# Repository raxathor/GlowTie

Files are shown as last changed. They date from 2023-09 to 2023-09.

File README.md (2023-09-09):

# Glowtie
## The light-up bowtie you control over Wifi!

This project/repository is inspired by Stephen Hawes.
https://www.youtube.com/@stephen_hawes
https://github.com/sphawes/glowtie
https://stephenhawes.com/glowtie/



Welcome to the source for the [Glowtie](http://glowtie.io)! The Glowtie is a light-up bowtie you control over Wifi. The onboard ESP8266 puts out an access point network you can connect to with your phone. Navigate to 192.168.4.1 in your browser and you'll find the Glowtie control page, where you can change the colors and the patterns of the lights.



This Github repository holds all the information needed to create a bowtie, from 3D models to schematics. This page will be helpful if you're looking to recreate the glowtie, or hack it!

For more information about the Glowtie, check out Glowtie.io.

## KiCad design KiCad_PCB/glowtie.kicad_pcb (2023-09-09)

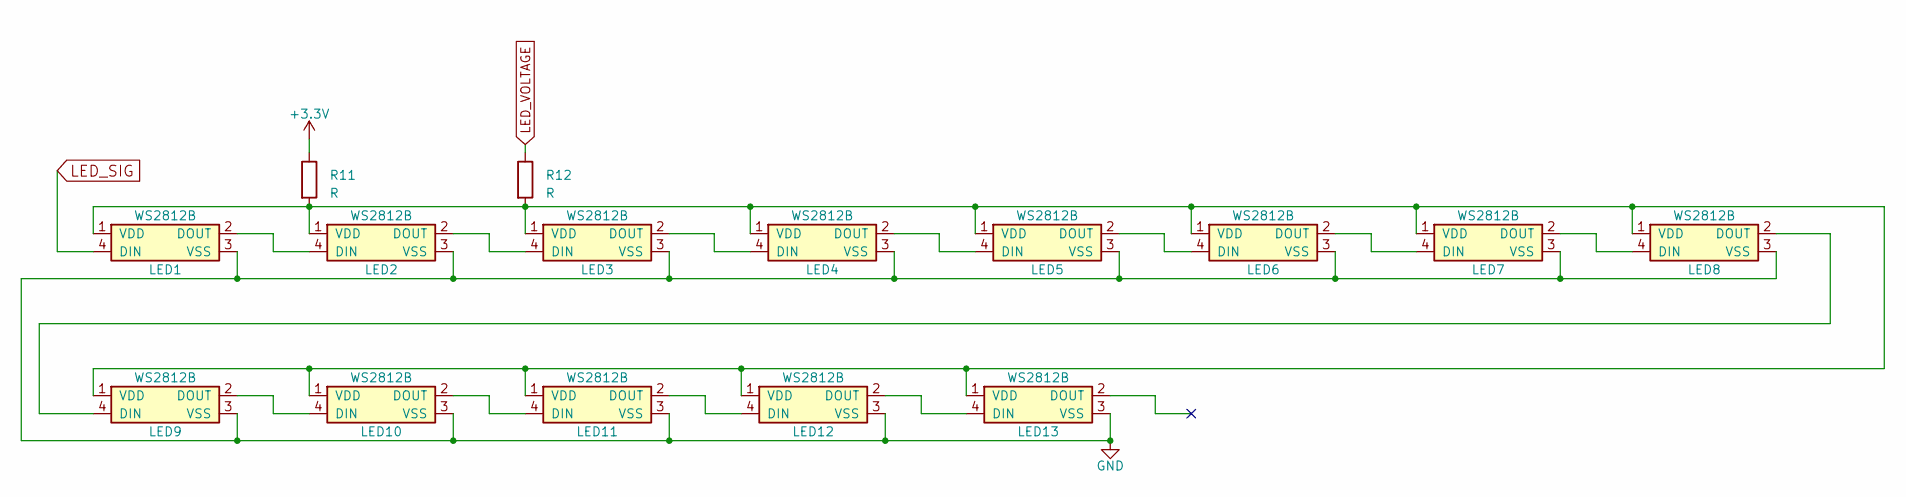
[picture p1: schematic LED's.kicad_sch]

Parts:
LED1, LED2, LED3, LED4, LED5, LED6, LED7, LED8, LED9, LED10, LED11, LED12, LED13: WS2812B
R11, R12: R; R_0603_1608Metric

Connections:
+3V3: R11.1; also elsewhere on the board
GND: LED1.3 (VSS), LED2.3 (VSS), LED3.3 (VSS), LED4.3 (VSS), LED5.3 (VSS), LED6.3 (VSS), LED7.3 (VSS), LED8.3 (VSS), LED9.3 (VSS), LED10.3 (VSS), LED11.3 (VSS), LED12.3 (VSS), LED13.3 (VSS); also elsewhere on the board
LED_SIG: LED1.4 (DIN); also elsewhere on the board
LED_VOLTAGE: R12.1; also elsewhere on the board
unnamed: LED1.2 (DOUT), LED2.4 (DIN)
unnamed: LED1.1 (VDD), LED2.1 (VDD), LED3.1 (VDD), LED4.1 (VDD), LED5.1 (VDD), LED6.1 (VDD), LED7.1 (VDD), LED8.1 (VDD), LED9.1 (VDD), LED10.1 (VDD), LED11.1 (VDD), LED12.1 (VDD), LED13.1 (VDD), R11.2, R12.2
unnamed: LED2.2 (DOUT), LED3.4 (DIN)
unnamed: LED3.2 (DOUT), LED4.4 (DIN)
unnamed: LED4.2 (DOUT), LED5.4 (DIN)
unnamed: LED5.2 (DOUT), LED6.4 (DIN)
unnamed: LED6.2 (DOUT), LED7.4 (DIN)
unnamed: LED7.2 (DOUT), LED8.4 (DIN)
unnamed: LED8.2 (DOUT), LED9.4 (DIN)
unnamed: LED9.2 (DOUT), LED10.4 (DIN)
unnamed: LED10.2 (DOUT), LED11.4 (DIN)
unnamed: LED11.2 (DOUT), LED12.4 (DIN)
unnamed: LED12.2 (DOUT), LED13.4 (DIN)

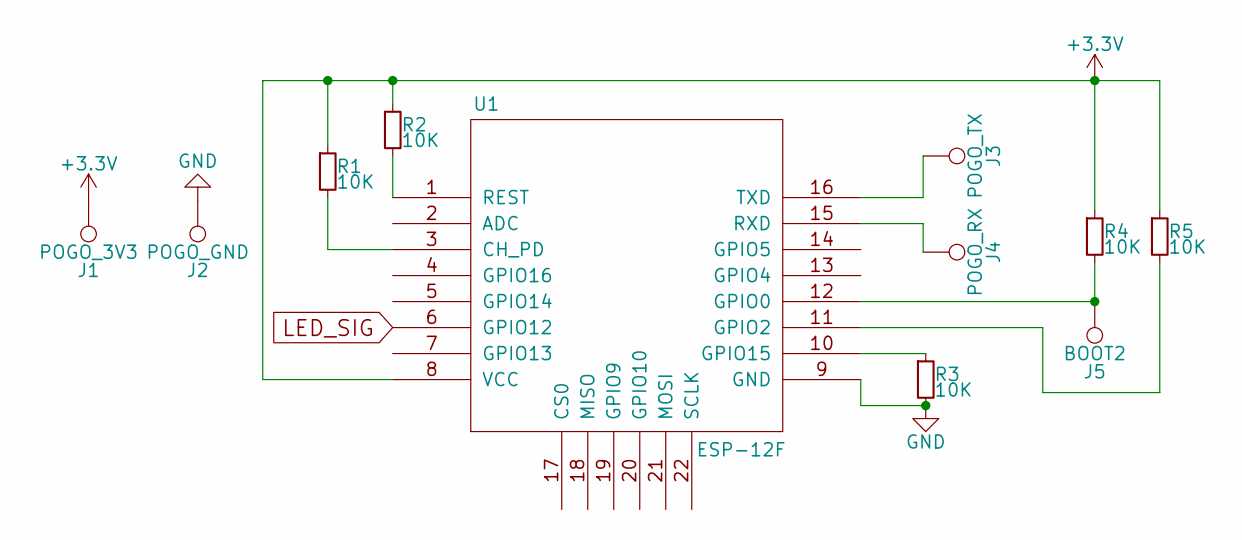
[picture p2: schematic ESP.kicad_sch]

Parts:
J1: POGO_3V3; TestPoint_Pad_D1.5mm
J2: POGO_GND; TestPoint_Pad_D1.5mm
J3: POGO_TX; TestPoint_Pad_D1.5mm
J4: POGO_RX; TestPoint_Pad_D1.5mm
J5: BOOT2; TestPoint_Pad_D1.5mm
R1, R2, R3, R4, R5: 10K; R_0805_2012Metric_Pad1.20x1.40mm_HandSolder
U1: ESP-12F; ESP-12E_SMD

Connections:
+3V3: J1.1, R1.1, R2.1, R4.1, R5.1, U1.8 (VCC); also elsewhere on the board
GND: J2.1, R3.2, U1.9 (GND); also elsewhere on the board
LED_SIG: U1.6 (GPIO12); also elsewhere on the board
unnamed: R1.2, U1.3 (CH_PD)
unnamed: J5.1, R4.2, U1.12 (GPIO0)
unnamed: R5.2, U1.11 (GPIO2)
unnamed: R3.1, U1.10 (GPIO15)
unnamed: R2.2, U1.1 (REST)
unnamed: J4.1, U1.15 (RXD)
unnamed: J3.1, U1.16 (TXD)

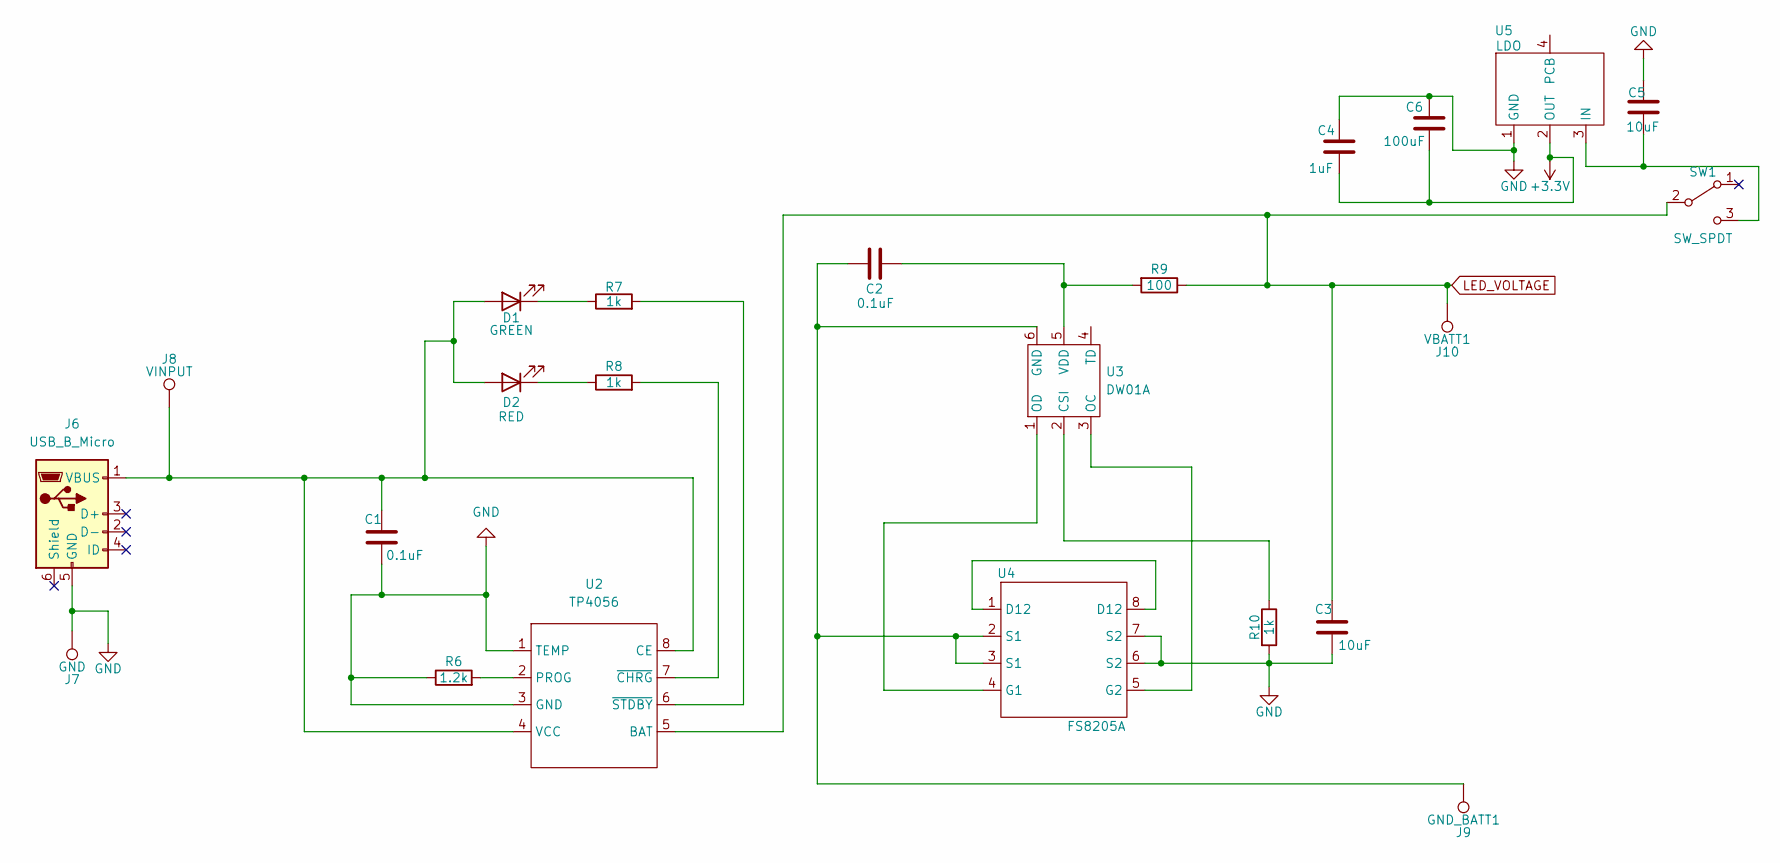
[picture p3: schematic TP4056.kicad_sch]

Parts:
C1, C2: 0.1uF; C_0805_2012Metric_Pad1.18x1.45mm_HandSolder
C3: 10uF; C_0805_2012Metric_Pad1.18x1.45mm_HandSolder
C4: 1uF; C_0805_2012Metric_Pad1.18x1.45mm_HandSolder
C5: 10uF; Tantalum_10uF
C6: 100uF; Tantalum_100uF
D1: GREEN; LED_0805_2012Metric_Pad1.15x1.40mm_HandSolder
D2: RED; LED_0805_2012Metric_Pad1.15x1.40mm_HandSolder
J6: USB_B_Micro; USB_Micro-B_Molex-105017-0001
J7: GND; TestPoint_Pad_D1.5mm
J8: VINPUT; TestPoint_Pad_D1.5mm
J9: GND_BATT1; TestPoint_Pad_D1.5mm
J10: VBATT1; TestPoint_Pad_D1.5mm
R6: 1.2k; R_0805_2012Metric_Pad1.20x1.40mm_HandSolder
R7, R8, R10: 1k; R_0805_2012Metric_Pad1.20x1.40mm_HandSolder
R9: 100; R_0805_2012Metric_Pad1.20x1.40mm_HandSolder
SW1: SW_SPDT; MSK12C02
U2: TP4056
U3: DW01A
U4: FS8205A
U5: LDO; AMS1117-3.3

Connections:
+3V3: C4.1, C6.1, U5.2 (OUT); also elsewhere on the board
GND: C1.2, C3.2, C4.2, C5.1, C6.2, J6.5 (GND), J7.1, R6.1, R10.2, U2.1 (TEMP), U2.3 (GND), U4.6 (S2), U4.7 (S2), U5.1 (GND); also elsewhere on the board
LED_VOLTAGE: C3.1, J10.1, R9.1, SW1.2 (B), U2.5 (BAT); also elsewhere on the board
unnamed: C1.1, D1.2 (A), D2.2 (A), J6.1 (VBUS), J8.1, U2.4 (VCC), U2.8 (CE)
unnamed: D1.1 (K), R7.1
unnamed: D2.1 (K), R8.1
unnamed: C5.2, SW1.3 (C), U5.3 (IN)
unnamed: R6.2, U2.2 (PROG)
unnamed: R8.2, U2.7 (~CHRG)
unnamed: R7.2, U2.6 (~STDBY)
unnamed: R10.1, U3.2 (CSI)
unnamed: C2.1, J9.1, U3.6 (GND), U4.2 (S1), U4.3 (S1)
unnamed: U3.3 (OC), U4.5 (G2)
unnamed: U3.1 (OD), U4.4 (G1)
unnamed: C2.2, R9.2, U3.5 (VDD)
unnamed: U4.1 (D12), U4.8 (D12)

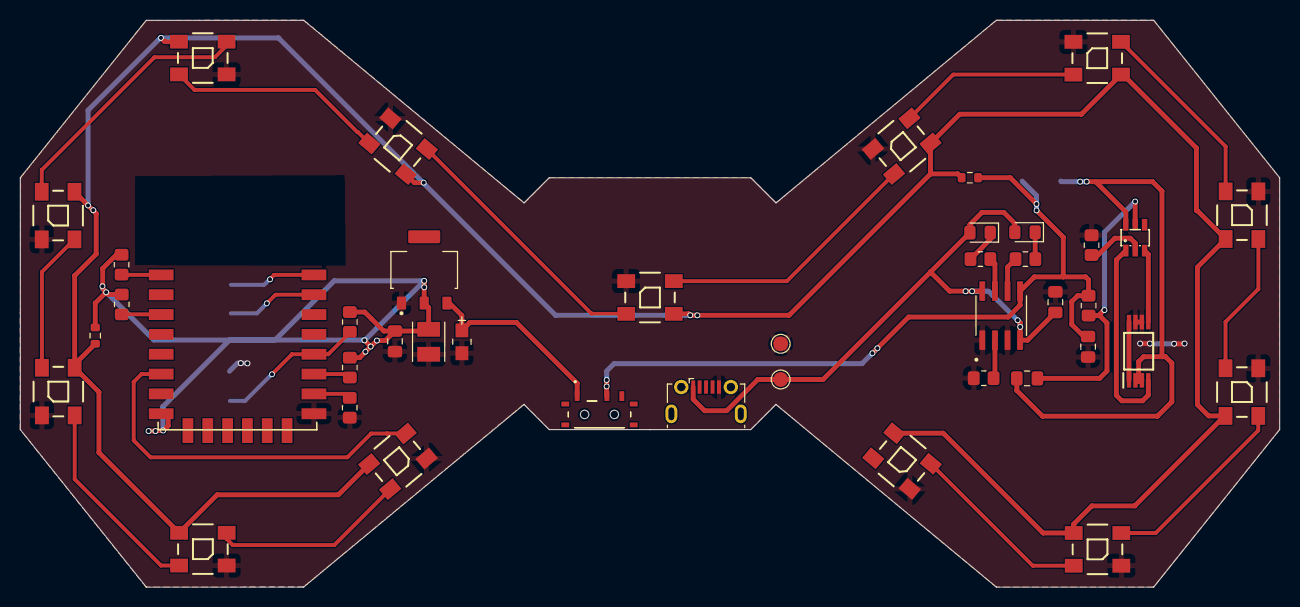
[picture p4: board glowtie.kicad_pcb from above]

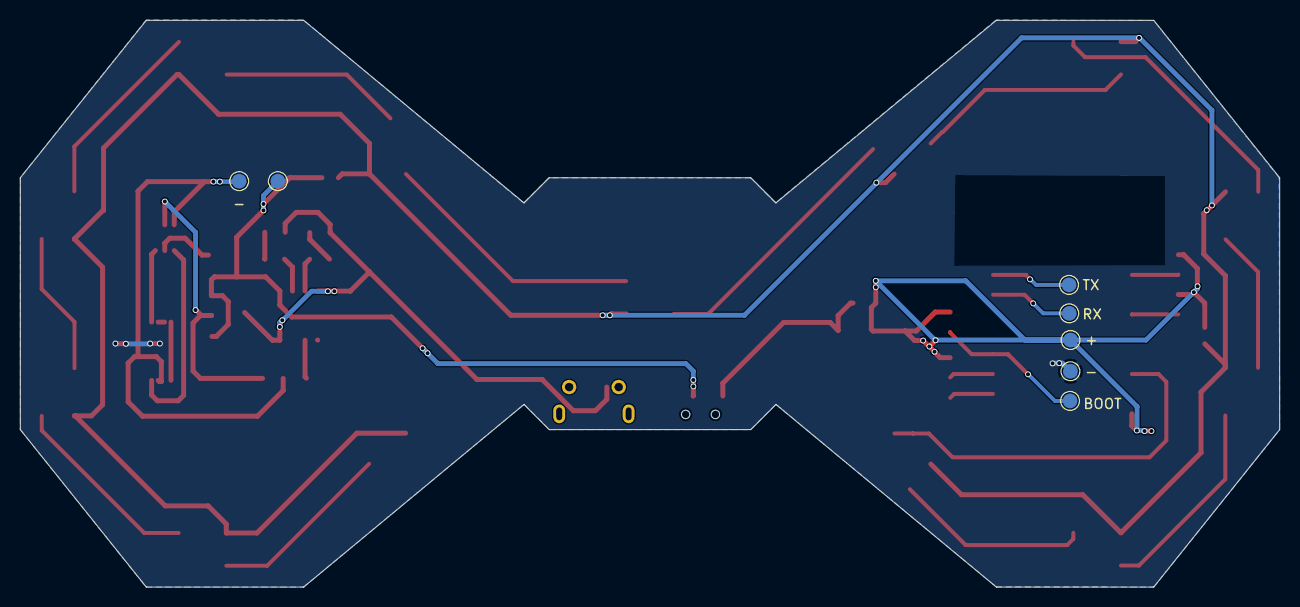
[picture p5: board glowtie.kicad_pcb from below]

Board: 2 copper layers, 127.0 x 57.2 mm, 49 parts (7 on the bottom side), 37 nets.

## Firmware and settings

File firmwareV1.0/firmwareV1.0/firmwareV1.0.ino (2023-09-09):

//Glowtie Firmware v1.0
//Stephen Hawes 2019
//TOOLS:
//Stringify HTML file:
//http://davidjwatts.com/youtube/esp8266/esp-convertHTM.html#
//Reference for sending data between site and server
//https://bitbucket.org/Remnis/neopixelwebserver/src/0ae6ce3b2122?at=master
//https://github.com/jasoncoon/esp8266-fastled-webserver/blob/master/data/index.htm

#include <Adafruit_NeoPixel.h>
#include <ESP8266WiFi.h>
#include <WiFiClient.h>
#include <ESP8266WebServer.h>
#include <EEPROM.h>

#define PIN            12
#define NUMPIXELS      13

#define SN "PizzaBowtie"

Adafruit_NeoPixel pixels = Adafruit_NeoPixel(NUMPIXELS, PIN, NEO_GRB + NEO_KHZ800);

ADC_MODE(ADC_VCC);

const char *ssid = SN;
const char *password = "pleaseletmein";

ESP8266WebServer server(80);

int const battCacheSize = 30;
int battCachePosition = 0;
int battCache[battCacheSize] = {3300, 3300, 3300, 3300, 3300, 3300, 3300, 3300, 3300, 3300, 3300, 3300, 3300, 3300, 3300, 3300, 3300, 3300, 3300, 3300, 3300, 3300, 3300, 3300, 3300, 3300, 3300, 3300, 3300, 3300};
int summedCache = 99000;
float avgBatt = 3300;
int newBatt = 0;

int delayVal = 8;
int btMode = 0;
int rVal = 0;
int gVal = 0;
int bVal = 0;
int brightness = 30;
int checkBattTimer = 0;
int prevMode = 0;

int ba = 0;
int bb = 0;
int bc = 0;
int bd = 0;
int bi = 0;

int pa = 0;
int pi = 0;

int ii = 0;

unsigned long prevMillis = millis();

void setup() {
  Serial.begin(115200);

  pixels.begin();

  //storing 4 eeprom values. the 0th is the saved mode, then the 1-3th are r, g, and b values, respectively. 4 bytes per int with 4 ints is 16 bytes:
  EEPROM.begin(512);

  btMode = EEPROM.read(0);
  rVal = EEPROM.read(4);
  gVal = EEPROM.read(8);
  bVal = EEPROM.read(12);

  //CHECKING BATTERY

  newBatt = ESP.getVcc();
  if (newBatt <= 3100) {
    btMode = 1;
    Serial.println("Battery low, going into low battery mode.");
  }

  //Animation
  for (int j = 0; j < 300; j++) {
    burst(50, 20, 0);
    delay(10);
  }

  //WIFI JAZZ
  Serial.print("Creating Glowtie netowork...");
  if (WiFi.softAP(ssid)) {
    Serial.println("Successfully started access point.");
  }
  else {
    Serial.println("Could not start access point.");
  }

  IPAddress myIP = WiFi.softAPIP();
  Serial.print("IP address: ");
  Serial.println(myIP);

  server.on("/", handleRoot);
  server.begin();

  //END WIFI STUFF

  checkBattTimer = millis();

}



void loop() {
  //yield();
  server.handleClient();
  //Checking battery value

  if (millis() >= checkBattTimer + 5000) {
    newBatt = ESP.getVcc();
    Serial.println(newBatt);
    if (newBatt <= 3100) {
      btMode = 1;
    }
    checkBattTimer = millis();
  }


  //OFF MODE
  if (btMode == 0) {
    if (prevMode != 0) {
      off();
      prevMode = 0;
    }
  }

  //LOW BATTERY MODE
  else if (btMode == 1) {
    if (prevMode != 1) {
      lowBatt();
      prevMode = 1;
    }
  }

  //SOLID COLOR MODE
  else if (btMode == 2) {
    if (prevMode != 2) {
      solid();
      prevMode = 2;
    }
  }

  //INFINITY MODE
  else if (btMode == 3) {
    if (prevMode != 3) {
      prevMillis = millis() - 71;
      prevMode = 3;
      ii = 0;
    }
    if (millis() > prevMillis + 70) {
      prevMillis = millis();
      infin(rVal, gVal, bVal);
    }
  }

  //PULSE MODE
  else if (btMode == 4) {
    if (prevMode != 4) {
      pi = 0;
      prevMode = 4;
    }
    if (millis() > prevMillis + 7) {
      prevMillis = millis();
      pulse(rVal, gVal, bVal);
    }
  }

  //BURST MODE
  else if (btMode == 5) {
    if (prevMode != 5) {
      bi = 0;
      prevMode = 5;
    }
    if (millis() > prevMillis + 10) {
      //Burst mode
      prevMillis = millis();
      burst(rVal, gVal, bVal);
    }
  }
}

void handleRoot() {
  //off();

  if (server.args() > 0) {
    int r = server.arg("red").toInt();
    int g = server.arg("green").toInt();
    int b = server.arg("blue").toInt();
    String btModeS = server.arg("mode");
    btMode = btModeS.toInt();

    int red = r / 3;
    int green = g / 3;
    int blue = b / 3;

    rVal = red;
    gVal = green;
    bVal = blue;

    EEPROM.write(0, btMode);
    EEPROM.write(4, rVal);
    EEPROM.write(8, gVal);
    EEPROM.write(12, bVal);
    EEPROM.commit();
  }

  //String html ="<!DOCTYPE html> <html> <head> <title>Glowtie</title> <style> body { background-color: #000000; font-family: \"Helvetica\"; color: #ffffff; } .slider{ width:90%; } #colorUpdate{ background-color: black; width:200px; height:40px; margin:auto; text-align: center; padding:20px; border-radius: 10px; } </style> <meta name=\"viewport\" content=\"width=device-width, height=device-height, initial-scale=1.0, user-scalable=0, minimum-scale=1.0, maximum-scale=1.0\" /> <script> console.log(\"Inline JS running.\"); function updateColor(){ var red = document.forms['settings'].red.value; var green = document.forms['settings'].green.value; var blue = document.forms['settings'].blue.value; var rgb = blue | (green << 8) | (red << 16); var color = \"#\" + (0x1000000 + rgb).toString(16).slice(1); document.getElementById(\"colorUpdate\").style.backgroundColor = color; } </script> </head> <body> <h1 id=\"colorUpdate\">Glowtie</h1> <form action=\"\" name=\"settings\" id=\"settings\" method=\"post\"> <!--Color: <input class=\"jscolor\" value=\"ffffff\" name=\"color\">--> Red:<br /> <input type=\"range\" class=\"slider\" min=\"0\" max=\"255\" value=\"127\" name=\"red\" onchange=\"updateColor()\"><br /> Green<br /> <input type=\"range\" class=\"slider\" min=\"0\" max=\"255\" value=\"127\" name=\"green\" onchange=\"updateColor()\"><br /> Blue<br /> <input type=\"range\" class=\"slider\" min=\"0\" max=\"255\" value=\"127\" name=\"blue\" onchange=\"updateColor()\"><br /> <input type=\"radio\" name=\"mode\" value=\"0\" checked> Off<br /> <input type=\"radio\" name=\"mode\" value=\"2\"> Solid<br /> <input type=\"radio\" name=\"mode\" value=\"3\"> Infinity<br /> <input type=\"radio\" name=\"mode\" value=\"4\"> Breathe<br /> <input type=\"radio\" name=\"mode\" value=\"5\"> Burst<br /><br /> <button onclick=\"document.forms['settings'].submit()\" type=\"button\">Send to Glowtie!</button> </form> </body> </html>";
  String html = "<!DOCTYPE html> <html> <head> <title>Glowtie</title> <style> body { background-color: #000000; font-family: \"Helvetica\"; color: #ffffff; } .slider { -webkit-appearance: none; /* Override default CSS styles */ appearance: none; width: 100%; /* Full-width */ margin:auto; margin-bottom:40px; margin-top:10px; height: 25px; /* Specified height */ background:black; /* Grey background */ outline: none; /* Remove outline */ opacity: 0.7; /* Set transparency (for mouse-over effects on hover) */ -webkit-transition: .2s; /* 0.2 seconds transition on hover */ transition: opacity .2s; border:3px solid white; } .slider::-webkit-slider-thumb { -webkit-appearance: none; /* Override default look */ appearance: none; width: 50px; /* Set a specific slider handle width */ height: 50px; /* Slider handle height */ background: white; /* Green background */ cursor: pointer; /* Cursor on hover */ border-radius: 5px; border: 1px solid black; } #sliderCont { width:70%; margin:auto; } #colorUpdate{ background-color: black; width:200px; height:40px; margin:auto; text-align: center; padding:20px; border-radius: 10px; font-family:'Courier New', Courier, monospace } .container { display: block; position: relative; padding-left: 80px; padding-top:5px; margin-bottom: 30px; cursor: pointer; font-size: 22px; font-family: \"Courier New\"; font-weight: bold; color:white; -webkit-user-select: none; -moz-user-select: none; -ms-user-select: none; user-select: none; } /* Hide the browser's default radio button */ .container input { position: absolute; opacity: 0; cursor: pointer; } /* Create a custom radio button */ .checkmark { position: absolute; top: 0; left: 0; height: 40px; width: 70px; background-color: white; border-radius: 10px; } /* On mouse-over, add a grey background color */ .container:hover input ~ .checkmark { background-color: #ccc; } /* When the radio button is checked, add a blue background */ .container input:checked ~ .checkmark { background-color: gold; } /* Create the indicator (the dot/circle - hidden when not checked) */ .checkmark:after { content: \"\"; position: absolute; display: none; } /* Show the indicator (dot/circle) when checked */ .container input:checked ~ .checkmark:after { display: block; } /* Style the indicator (dot/circle) */ .container .checkmark:after { top: 15px; left: 15px; width: 40px; height: 10px; border-radius: 3px; background: black; } </style> <meta name=\"viewport\" content=\"width=device-width, height=device-height, initial-scale=1.0, user-scalable=0, minimum-scale=1.0, maximum-scale=1.0\" /> <script> console.log(\"Inline JS running.\"); function updateColor(){ var red = document.forms['settings'].red.value; var green = document.forms['settings'].green.value; var blue = document.forms['settings'].blue.value; var rgb = blue | (green << 8) | (red << 16); var color = \"#\" + (0x1000000 + rgb).toString(16).slice(1); document.getElementById(\"colorUpdate\").style.backgroundColor = color; } </script> </head> <body> <h1 id=\"colorUpdate\">Glowtie</h1> <form action=\"\" name=\"settings\" id=\"settings\" method=\"post\"> <!--Color: <input class=\"jscolor\" value=\"ffffff\" name=\"color\">--> <div id=\"sliderCont\"> RED<br /> <input type=\"range\" class=\"slider\" min=\"0\" max=\"255\" value=\"127\" name=\"red\" onchange=\"updateColor()\"><br /> GREEN<br /> <input type=\"range\" class=\"slider\" min=\"0\" max=\"255\" value=\"127\" name=\"green\" onchange=\"updateColor()\"><br /> BLUE<br /> <input type=\"range\" class=\"slider\" min=\"0\" max=\"255\" value=\"127\" name=\"blue\" onchange=\"updateColor()\"><br /> </div> <br /> <div style=\"width:200px;margin:auto;\"> <!-- <input class=\"radio\" type=\"radio\" name=\"mode\" value=\"0\" checked> Off<br /> <input class=\"radio\" type=\"radio\" name=\"mode\" value=\"2\"> Solid<br /> <input class=\"radio\" type=\"radio\" name=\"mode\" value=\"3\"> Infinity<br /> <input class=\"radio\" type=\"radio\" name=\"mode\" value=\"4\"> Breathe<br /> <input class=\"radio\" type=\"radio\" name=\"mode\" value=\"5\"> Burst<br /><br />--> <label class=\"container\">Off <input type=\"radio\" checked=\"checked\" name=\"mode\" value=\"0\"> <span class=\"checkmark\"></span> </label> <label class=\"container\">Solid <input type=\"radio\" name=\"mode\" value=\"2\"> <span class=\"checkmark\"></span> </label> <label class=\"container\">Infinity <input type=\"radio\" name=\"mode\" value=\"3\"> <span class=\"checkmark\"></span> </label> <label class=\"container\">Breathe <input type=\"radio\" name=\"mode\" value=\"4\"> <span class=\"checkmark\"></span> </label> <label class=\"container\">Burst <input type=\"radio\" name=\"mode\" value=\"5\"> <span class=\"checkmark\"></span> </label> <button style=\"width:150px;height:50px;background-color:gold;color:black;position:relative;margin-left:25px;margin-top:20px;font-family: 'Courier New', Courier, monospace;font-size:20px;border:0px;border-radius:10px;\" onclick=\"document.forms['settings'].submit()\" type=\"button\">UPDATE</button> </div> </form> </body> </html>";


  server.send(200, "text/html", html);


}

void updateAvgBatt() {
  newBatt = ESP.getVcc();
  summedCache = summedCache - battCache[battCachePosition];
  summedCache = summedCache + newBatt;
  battCache[battCachePosition] = newBatt;

  if (battCachePosition == (battCacheSize - 1)) {
    battCachePosition = 0;
  }
  else {
    battCachePosition++;
  }
  avgBatt = summedCache / battCacheSize;

}

void off() {
  pixels.setPixelColor(0, pixels.Color(0, 0, 0));
  pixels.setPixelColor(1, pixels.Color(0, 0, 0));
  pixels.setPixelColor(2, pixels.Color(0, 0, 0));
  pixels.setPixelColor(3, pixels.Color(0, 0, 0));
  pixels.setPixelColor(4, pixels.Color(0, 0, 0));
  pixels.setPixelColor(5, pixels.Color(0, 0, 0));
  pixels.setPixelColor(6, pixels.Color(0, 0, 0));
  pixels.setPixelColor(7, pixels.Color(0, 0, 0));
  pixels.setPixelColor(8, pixels.Color(0, 0, 0));
  pixels.setPixelColor(9, pixels.Color(0, 0, 0));
  pixels.setPixelColor(10, pixels.Color(0, 0, 0));
  pixels.setPixelColor(11, pixels.Color(0, 0, 0));
  pixels.setPixelColor(12, pixels.Color(0, 0, 0));
  pixels.show();
}

void lowBatt() {
  pixels.setPixelColor(0, pixels.Color(0, 0, 0));
  pixels.setPixelColor(1, pixels.Color(0, 0, 0));
  pixels.setPixelColor(2, pixels.Color(0, 0, 0));
  pixels.setPixelColor(3, pixels.Color(0, 0, 0));
  pixels.setPixelColor(4, pixels.Color(0, 0, 0));
  pixels.setPixelColor(5, pixels.Color(0, 0, 0));
  pixels.setPixelColor(6, pixels.Color(50, 0, 0));
  pixels.setPixelColor(7, pixels.Color(0, 0, 0));
  pixels.setPixelColor(8, pixels.Color(0, 0, 0));
  pixels.setPixelColor(9, pixels.Color(0, 0, 0));
  pixels.setPixelColor(10, pixels.Color(0, 0, 0));
  pixels.setPixelColor(11, pixels.Color(0, 0, 0));
  pixels.setPixelColor(12, pixels.Color(0, 0, 0));

  pixels.show();
}

void solid() {
  pixels.setPixelColor(0, pixels.Color(rVal, gVal, bVal));
  pixels.setPixelColor(1, pixels.Color(rVal, gVal, bVal));
  pixels.setPixelColor(2, pixels.Color(rVal, gVal, bVal));
  pixels.setPixelColor(3, pixels.Color(rVal, gVal, bVal));
  pixels.setPixelColor(4, pixels.Color(rVal, gVal, bVal));
  pixels.setPixelColor(5, pixels.Color(rVal, gVal, bVal));
  pixels.setPixelColor(6, pixels.Color(rVal, gVal, bVal));
  pixels.setPixelColor(7, pixels.Color(rVal, gVal, bVal));
  pixels.setPixelColor(8, pixels.Color(rVal, gVal, bVal));
  pixels.setPixelColor(9, pixels.Color(rVal, gVal, bVal));
  pixels.setPixelColor(10, pixels.Color(rVal, gVal, bVal));
  pixels.setPixelColor(11, pixels.Color(rVal, gVal, bVal));
  pixels.setPixelColor(12, pixels.Color(rVal, gVal, bVal));

  pixels.show();
}

void infin(int red, int green, int blue) {

  if (ii == 0) {
    pixels.setPixelColor(6, pixels.Color(0, 0, 0));
    pixels.setPixelColor(0, pixels.Color(red, green, blue));
    pixels.show();
  }
  else if (ii == 1) {
    pixels.setPixelColor(1, pixels.Color(red, green, blue)); // Moderately bright green color.
    pixels.setPixelColor(0, pixels.Color(0, 0, 0));
    pixels.show(); // This sends the updated pixel color to the hardware.
  }
  else if (ii == 2) {
    pixels.setPixelColor(2, pixels.Color(red, green, blue)); // Moderately bright green color.
    pixels.setPixelColor(1, pixels.Color(0, 0, 0));
    pixels.show();
  }
  else if (ii == 3) {
    pixels.setPixelColor(3, pixels.Color(red, green, blue)); // Moderately bright green color.
    pixels.setPixelColor(2, pixels.Color(0, 0, 0));
    pixels.show();
  }
  else if (ii == 4) {
    pixels.setPixelColor(4, pixels.Color(red, green, blue)); // Moderately bright green color.
    pixels.setPixelColor(3, pixels.Color(0, 0, 0));
    pixels.show();
  }
  else if (ii == 5) {
    pixels.setPixelColor(5, pixels.Color(red, green, blue)); // Moderately bright green color.
    pixels.setPixelColor(4, pixels.Color(0, 0, 0));
    pixels.show();
  }
  else if (ii == 6) {
    pixels.setPixelColor(6, pixels.Color(red, green, blue)); // Moderately bright green color.
    pixels.setPixelColor(5, pixels.Color(0, 0, 0));
    pixels.show();
  }
  else if (ii == 7) {
    pixels.setPixelColor(12, pixels.Color(red, green, blue)); // Moderately bright green color.
    pixels.setPixelColor(6, pixels.Color(0, 0, 0));
    pixels.show();
  }
  else if (ii == 8) {
    pixels.setPixelColor(11, pixels.Color(red, green, blue)); // Moderately bright green color.
    pixels.setPixelColor(12, pixels.Color(0, 0, 0));
    pixels.show();
  }
  else if (ii == 9) {
    pixels.setPixelColor(10, pixels.Color(red, green, blue)); // Moderately bright green color.
    pixels.setPixelColor(11, pixels.Color(0, 0, 0));
    pixels.show();
  }
  else if (ii == 10) {
    pixels.setPixelColor(9, pixels.Color(red, green, blue)); // Moderately bright green color.
    pixels.setPixelColor(10, pixels.Color(0, 0, 0));
    pixels.show();
  }
  else if (ii == 11) {
    pixels.setPixelColor(8, pixels.Color(red, green, blue)); // Moderately bright green color.
    pixels.setPixelColor(9, pixels.Color(0, 0, 0));
    pixels.show();
  }
  else if (ii == 12) {
    pixels.setPixelColor(7, pixels.Color(red, green, blue)); // Moderately bright green color.
    pixels.setPixelColor(8, pixels.Color(0, 0, 0));
    pixels.show();
  }
  else if (ii == 13) {
    pixels.setPixelColor(6, pixels.Color(red, green, blue)); // Moderately bright green color.
    pixels.setPixelColor(7, pixels.Color(0, 0, 0));
    pixels.show();
  }


  if (ii > 12) {
    ii = 0;
  }
  else {
    ii = ii + 1;
  }

}

void pulse(int red, int green, int blue) {
  if (pi >= 200) {
    pi = 0;
  }

  //Brightness value counter
  if (pi <= 50) {
    pa = pa + 1;
  }
  if (pi > 50 && pa > 0) {
    pa = pa - 1;
  }

  float fA = float(pa);

  pixels.setPixelColor(6, pixels.Color(fA / 50 * red, fA / 50 * green, fA / 50 * blue));

  pixels.setPixelColor(5, pixels.Color(fA / 50 * red, fA / 50 * green, fA / 50 * blue));
  pixels.setPixelColor(0, pixels.Color(fA / 50 * red, fA / 50 * green, fA / 50 * blue));
  pixels.setPixelColor(7, pixels.Color(fA / 50 * red, fA / 50 * green, fA / 50 * blue));
  pixels.setPixelColor(12, pixels.Color(fA / 50 * red, fA / 50 * green, fA / 50 * blue));

  pixels.setPixelColor(1, pixels.Color(fA / 50 * red, fA / 50 * green, fA / 50 * blue));
  pixels.setPixelColor(4, pixels.Color(fA / 50 * red, fA / 50 * green, fA / 50 * blue));
  pixels.setPixelColor(8, pixels.Color(fA / 50 * red, fA / 50 * green, fA / 50 * blue));
  pixels.setPixelColor(11, pixels.Color(fA / 50 * red, fA / 50 * green, fA / 50 * blue));

  pixels.setPixelColor(2, pixels.Color(fA / 50 * red, fA / 50 * green, fA / 50 * blue));
  pixels.setPixelColor(3, pixels.Color(fA / 50 * red, fA / 50 * green, fA / 50 * blue));
  pixels.setPixelColor(9, pixels.Color(fA / 50 * red, fA / 50 * green, fA / 50 * blue));
  pixels.setPixelColor(10, pixels.Color(fA / 50 * red, fA / 50 * green, fA / 50 * blue));

  pixels.show();
  pi = pi + 1;
}


void burst(int red, int green, int blue) {
  if (bi >= 300) {
    bi = 0;
  }

  // a column
  if (bi <= 50) {
    ba = ba + 1;
  }
  if (bi > 50 && ba > 0) {
    ba = ba - 1;
  }

  // b column
  if (bi >= 25 && bi <= 75) {
    bb = bb + 1;
  }
  if (bi > 75 && bb > 0) {
    bb = bb - 1;
  }

  //c column
  if (bi >= 50 && bi <= 100) {
    bc = bc + 1;
  }
  if (bi > 100 && bc > 0) {
    bc = bc - 1;
  }

  //d column
  if (bi >= 75 && bi <= 125) {
    bd = bd + 1;
  }
  if (bi > 125 && bd > 0) {
    bd = bd - 1;
  }

  float fA = float(ba);
  float fB = float(bb);
  float fC = float(bc);
  float fD = float(bd);

  pixels.setPixelColor(6, pixels.Color(fA / 50 * red, fA / 50 * green, fA / 50 * blue));

  pixels.setPixelColor(5, pixels.Color(fB / 50 * red, fB / 50 * green, fB / 50 * blue));
  pixels.setPixelColor(0, pixels.Color(fB / 50 * red, fB / 50 * green, fB / 50 * blue));
  pixels.setPixelColor(7, pixels.Color(fB / 50 * red, fB / 50 * green, fB / 50 * blue));
  pixels.setPixelColor(12, pixels.Color(fB / 50 * red, fB / 50 * green, fB / 50 * blue));

  pixels.setPixelColor(1, pixels.Color(fC / 50 * red, fC / 50 * green, fC / 50 * blue));
  pixels.setPixelColor(4, pixels.Color(fC / 50 * red, fC / 50 * green, fC / 50 * blue));
  pixels.setPixelColor(8, pixels.Color(fC / 50 * red, fC / 50 * green, fC / 50 * blue));
  pixels.setPixelColor(11, pixels.Color(fC / 50 * red, fC / 50 * green, fC / 50 * blue));

  pixels.setPixelColor(2, pixels.Color(fD / 50 * red, fD / 50 * green, fD / 50 * blue));
  pixels.setPixelColor(3, pixels.Color(fD / 50 * red, fD / 50 * green, fD / 50 * blue));
  pixels.setPixelColor(9, pixels.Color(fD / 50 * red, fD / 50 * green, fD / 50 * blue));
  pixels.setPixelColor(10, pixels.Color(fD / 50 * red, fD / 50 * green, fD / 50 * blue));

  pixels.show();
  bi = bi + 1;
}
